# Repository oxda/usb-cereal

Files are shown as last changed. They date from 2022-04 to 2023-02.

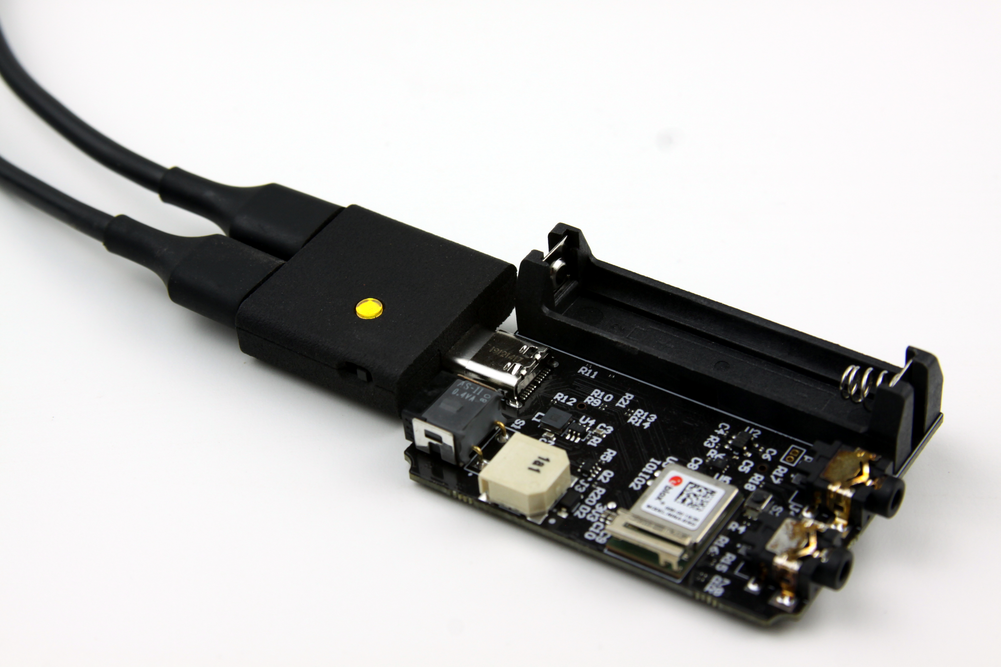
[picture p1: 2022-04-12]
img/edit_IMG_1961.JPG

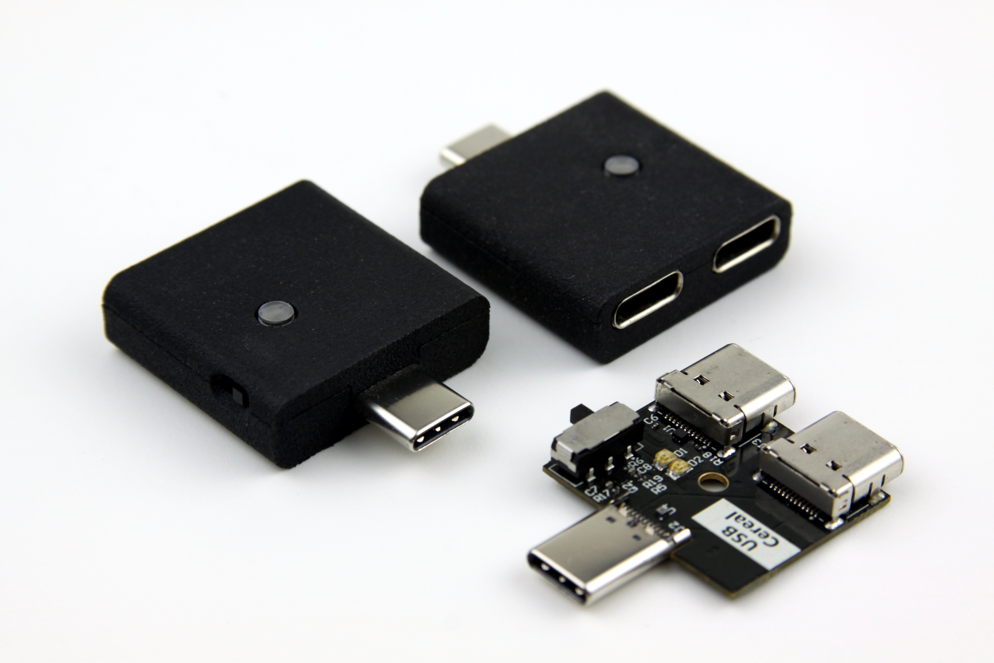
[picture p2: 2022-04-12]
img/edit_IMG_1957.JPG

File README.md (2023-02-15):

# USB-Cereal
USB-Cereal is a powerful, fully open source development tool that simplifies testing, development, debugging, and manufacturing of devices that utilize USB-C. Using USB-C’s extended capabilities this unique hardware saves time and effort through simplified debug and factory log capture, as well as firmware update procedures.

**Availability:** CrowdSupply campaign: https://www.crowdsupply.com/0xda/usb-cereal

**Documentation:** [This repo's wiki](https://github.com/oxda/usb-cereal/wiki).

**Repo structure**
- /docs [WIP] contains PDF schematics and usage instructions.
- /mcad [WIP] contains mechanical enclosure.
- /ecad [WIP] contains entire USB-Cereal project done in Altium.

**FT232RQ vs FT232RNQ vs CP2102N**
As FTDI chips have intermittent supply issues we have also qualified CP2102N for the application. This IC is widely available, and is generally equally well equipped and compatible with major OSes. 

# Important Notes
Initial release contains a mistake where CC1/CC2 pins are tied together and share a single 5.1k pull-down resistor. This causes the USB-Cereal to not be compatible with the full USB-C cables. 0xDA's devices have corrected this mistake, but please beware if you have forked the design earlier.

# License
All the work is licensed under Apache 2.0 license. Changes from the original project: BOM optimization, layout adjustments, addition of the CP2102N and FT232RNQ versions.

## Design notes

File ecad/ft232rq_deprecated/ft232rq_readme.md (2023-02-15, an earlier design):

USB-Cereal ECAD files for FT232RQ variant.

**Note:** The design contains several mistakes - the CC1/CC2 share a legacy mode resistor, while they should be split into two. The overvoltage clamp presents too much capacitance on the TX/RX lines which prevents datarates above 576000.

**The design is frozen and deprecated. FT232RQ is an NRND component.** Please see updated FT232RNQ variant for the latest designs.

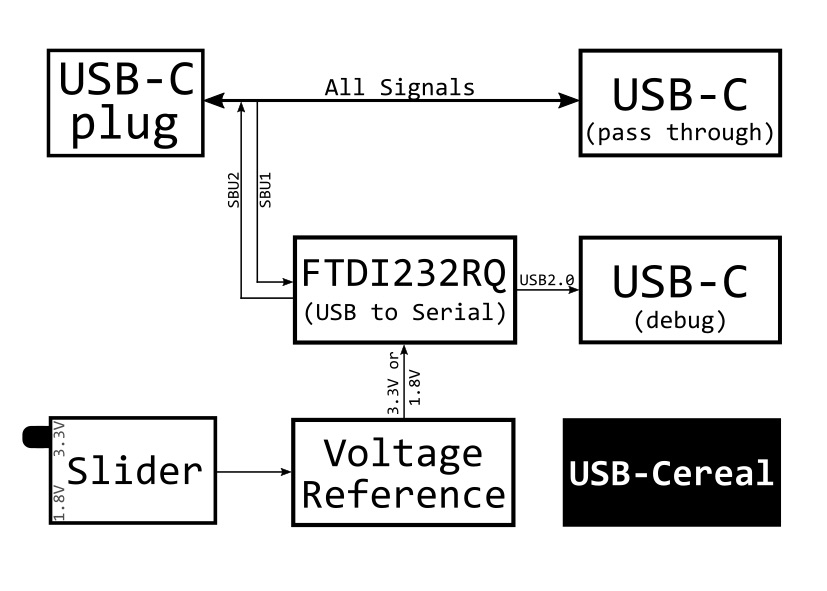
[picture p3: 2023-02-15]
img/usb-cereal-diagram.jpg

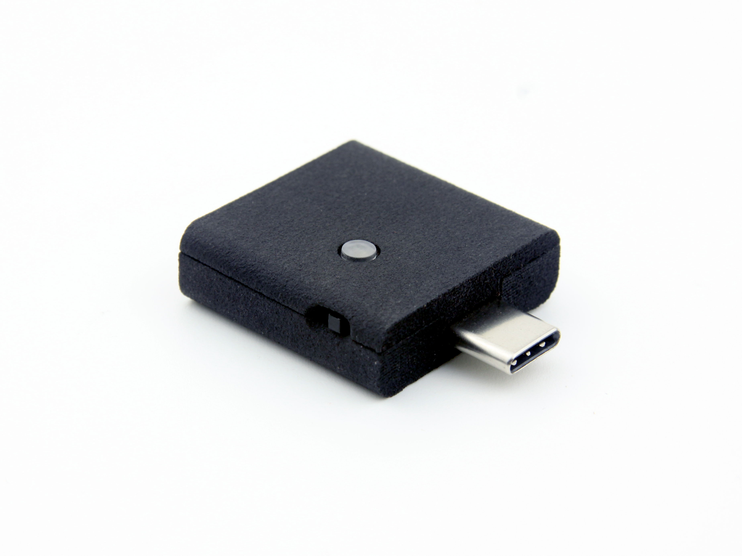
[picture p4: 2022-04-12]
img/edit_IMG_1848.JPG

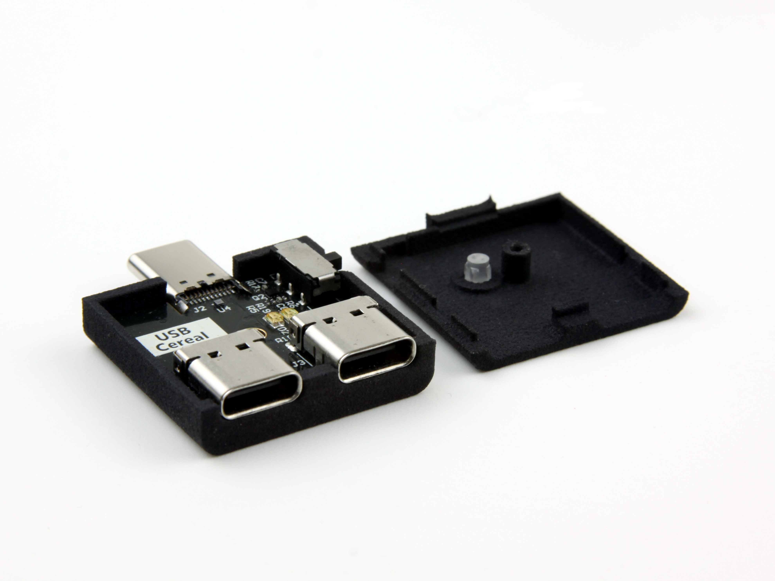
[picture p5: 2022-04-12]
img/edit_IMG_1966.JPG

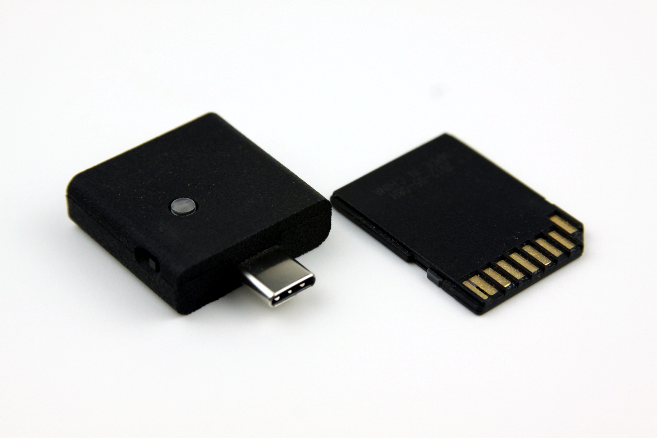
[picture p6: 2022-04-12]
img/edit_IMG_1954.JPG

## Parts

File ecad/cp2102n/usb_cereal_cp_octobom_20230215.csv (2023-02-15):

Query | Qty | Manufacturer | MPN | Part Description | Description | Schematic Reference
GCM155C71A105KE38D | 3 | Murata | GCM155C71A105KE38D | Multilayer Ceramic Capacitor, 1 uF, 10 V, ± 10%, X7S, 0402 [1005 Metric] | CAP CER 1UF 10V X7S 0402 | C1, C9, C10
GRM152R61A104KE19D | 2 | Murata | GRM152R61A104KE19D | Multilayer Ceramic Capacitor, 0.1 uF, 10 V, ± 10%, X5R, 0402 [1005 Metric] | CAP CER 0.1UF 10V X5R 0402 | C2, C5
ZRB15XR61A475KE01D | 2 | Murata | ZRB15XR61A475KE01D | Multilayer Ceramic Capacitor, 4.7 uF, 10 V, ± 10%, X5R, 0402 [1005 Metric] | CAP CER 4.7UF 10V X5R 0402 | C3, C4
GCM155R71E103KA37D | 1 | Murata | GCM155R71E103KA37D | Multilayer Ceramic Capacitor, 0.01 uF, 25 V, ± 10%, X7R, 0402 [1005 Metric] | CAP CER 10000PF 25V X7R 0402 | C6
LTST-C171GKT | 1 | Lite-On | LTST-C171GKT | LED Low-Power Uni-Color Green 565nm 2.1V 2-Pin Chip LED T/R | LED | D1
LTST-C171KSKT | 1 | Lite-On | LTST-C171KSKT | Yellow 2 x 1.25 x 0.8 mm 130° Water Clear 50 mcd 2 V LED Surface Mount | LED | D2
UJ32-C-H-G-SMT-TR | 2 | CUI Devices | UJ32-C-H-G-SMT-TR | Type C, USB 3.2 Gen 2x2, 20 Gbps, 20 Vac, 5 A, Horizontal, Gold Flash, Surface Mount, USB Receptacle | Type C, USB 3.1 Gen 2, 5 A, Right Angle, Surface Mount _SMT_ , USB Receptacle | J1, J3
USB4155-03-C | 1 | Global Connector Technology | USB4155-03-C | Usb Conn, 3.1 Type C, Plug, 24POS, SMT Rohs Compliant: Yes |  | J2
ERJ-2GE0R00X | 3 | Panasonic | ERJ-2GE0R00X | SMD Chip Resistor, Jumper, 0 ohm, 100 mW, 0402 [1005 Metric], Thick Film, General Purpose | RES SMD 0.0OHM JUMPER 1/10W 0402 | R1, R2, R16
ERJ-PA2F1001X | 1 | Panasonic | ERJ-PA2F1001X | Res Thick Film 0402 1K Ohm 1% 1/5W ±100ppm/°C Molded SMD Punched Paper T/R | RES SMD 1K OHM 1% 1/5W 0402 | R5
ERJ-2RKF2700X | 1 | Panasonic | ERJ-2RKF2700X | Res Thick Film 0402 270 Ohm 1% 0.1W(1/10W) +/-100ppm/C Molded SMD Automotive Punched T/R | RES SMD 270 OHM 1% 1/10W 0402 | R6
ERJ-2RKF5362X | 2 | Panasonic | ERJ-2RKF5362X | Res Thick Film 0402 53.6K Ohm 1% 1/10W ±100ppm/°C Molded SMD SMD Punched Carrier T/R | RES SMD 53.6K OHM 1% 1/10W 0402 | R9, R10
ERJ-2RKF2212X | 3 | Panasonic | ERJ-2RKF2212X | Resistor Thick Film 0402 22.1K Ohm 1% 0.1W (1/10W) ±100ppm/C Molded Surface Mount Automotive | RES SMD 22.1K OHM 1% 1/10W 0402 | R11, R15, R20
ERJ-2RKF3012X | 1 | Panasonic | ERJ-2RKF3012X | Res Thick Film 0402 30.1K Ohm 1% 1/10W +/-100ppm/ßC Molded SMD Punched Carrier T/R | RES SMD 30.1K OHM 1% 1/10W 0402 | R12
ERJ-2RKF5101X | 2 | Panasonic | ERJ-2RKF5101X | Res Thick Film 0402 5.1K Ohm 1% 1/10W ±100ppm/°C Molded SMD Punched Carrier T/R | RES SMD 5.1K OHM 1% 1/10W 0402 | R18, R22
ERJ-2RKF4752X | 1 | Panasonic | ERJ-2RKF4752X | Res Thick Film 0402 47.5K Ohm 1% 1/10W +/-100ppm/ßC Molded SMD Punched Carrier T/R | RES SMD 47.5K OHM 1% 1/10W 0402 | R21
JS202011JAQN | 1 | C&K Components | JS202011JAQN | Switch Slide ON ON DPDT Side Slide 0.3A 6VDC J-Bend SMD T/R | Slide Switch DPDT Surface Mount, Right Angle | S1
ESDR0502NMUTAG | 2 | onsemi | ESDR0502NMUTAG | ESDR0502N Series 5.5 V 0.3 pF Uni-Directional ESD Suppressor Diode Array -UDFN-6 | Ultra Low Capacitance ESD Protection Array for High Speed Data Line Protection, 6-Pin UDFN, Pb-Free, Tape and Reel | U1, U4
TPS77401DGK | 1 | Texas Instruments | TPS77401DGK | LDO Regulator Pos 1.5V to 5.5V 0.25A 8-Pin VSSOP Tube | Single Output Fast Transient Response LDO, 250 mA, Adjustable 1.5 to 5.5 V Output, 2.7 to 10 V Input, with Power Good Output, 8-pin MSOP (DGK), -40 to 125 degC, Green (RoHS & no Sb/Br) | U2
CP2102N-A02-GQFN24R | 1 | Silicon Labs | CP2102N-A02-GQFN24R | Interface IC full speed USB to UART bridge USB 2.0 3.3V, CP2102N-A02-GQFN24R, VFQFN-24 | USB Bridge, USB to UART USB 2.0 UART Interface 24-QFN _4x4_ | U3

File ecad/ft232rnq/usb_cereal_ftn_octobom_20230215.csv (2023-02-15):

Query | Qty | Manufacturer | MPN | Part Description | Description | Schematic Reference
JS202011JAQN | 1 | C&K Components | JS202011JAQN | Switch Slide ON ON DPDT Side Slide 0.3A 6VDC J-Bend SMD T/R | Slide Switch DPDT Surface Mount, Right Angle | S1
UJ32-C-H-G-SMT-TR | 2 | CUI Devices | UJ32-C-H-G-SMT-TR | Type C, USB 3.2 Gen 2x2, 20 Gbps, 20 Vac, 5 A, Horizontal, Gold Flash, Surface Mount, USB Receptacle | Type C, USB 3.1 Gen 2, 5 A, Right Angle, Surface Mount _SMT_ , USB Receptacle | J1, J3
FT232RNQ | 1 | FTDI | FT232RNQ-REEL | USB to Full Handshake UART Interface QFN32 (not offered in your region) | USB Bridge, USB to UART USB 2.0 UART Interface 32-QFN _5x5_ | U3
DX07P024AJ1R1500 | 1 | JAE Electronics | DX07P024AJ1R1500 | Conn Plug USB3.1 Typec Brd Edge | USB-C _USB TYPE-C_ USB 3.1 _USB 3.1 Gen 2, Superspeed+_ Plug Connector 24 Position Board Edge, Straddle Mount | J2
LTST-C171GKT | 1 | Lite-On | LTST-C171GKT | LED Low-Power Uni-Color Green 565nm 2.1V 2-Pin Chip LED T/R | LED | D1
LTST-C171KSKT | 1 | Lite-On | LTST-C171KSKT | Yellow 2 x 1.25 x 0.8 mm 130° Water Clear 50 mcd 2 V LED Surface Mount | LED | D2
GRM033R60J105MEA2D | 4 | Murata | GRM033R60J105MEA2D | Multilayer Ceramic Capacitor, 1 uF, 6.3 V, ± 20%, X5R, 0201 [0603 Metric] | CAP CER 1UF 6.3V X5R 0201 | C1, C2, C9, C10
GRM033R61A103KA01J | 1 | Murata | GRM033R61A103KA01J | 0201 10 nF 10 V ±10% Tolerance X5R SMT Multilayer Ceramic Capacitor | CAP CER 10000PF 10V X5R 0201 | C6
GRM033R61A104KE15D | 2 | Murata | GRM033R61A104KE15D | Multilayer Ceramic Capacitor, 0.1 uF, 10 V, ± 10%, X5R, 0201 [0603 Metric] | CAP CER 0.1UF 10V X5R 0201 | C3, C5
GRM033R61A225KE47D | 2 | Murata | GRM033R61A225KE47D | Multilayer Ceramic Capacitor, 2.2 uF, 10 V, ± 10%, X5R, 0201 [0603 Metric] | CAP CER 2.2UF 10V X5R 0201 | C7, C8
GRM035R60J475ME15D | 1 | Murata | GRM035R60J475ME15D | Multilayer Ceramic Capacitor, 4.7 uF, 6.3 V, ± 20%, X5R, 0201 [0603 Metric] | CAP CER 4.7UF 6.3V X5R 0201 | C4
PMDXB600UNEZ | 2 | Nexperia | PMDXB600UNEZ | Dual Mosfet, Dual N Channel, 600 Ma, 20 V, 0.47 Ohm, 4.5 V, 700 Mv | Dual N-Channel Trench MOSFET, 20 V, 0.6 A, -55 to 150 degC, 8-Pin SOT1216 | Q1, Q2
ESD7383NCTBG | 1 | onsemi | ESD7383NCTBG | ESD Protection, 3-Line, Very Low Capacitance, for USB | USB-OTG 3-Line Protection, 4-Pin WLCSP, Pb-Free, Tape and Reel | U4
ESDR0502NMUTAG | 1 | onsemi | ESDR0502NMUTAG | ESDR0502N Series 5.5 V 0.3 pF Uni-Directional ESD Suppressor Diode Array -UDFN-6 | Ultra Low Capacitance ESD Protection Array for High Speed Data Line Protection, 6-Pin UDFN, Pb-Free, Tape and Reel | U1
ERJ-1GEF3012C | 3 | Panasonic | ERJ-1GEF3012C | Res Thick Film 0201 30.1K Ohm 1% 1/20W ±200ppm/°C Molded SMD Pressed Carrier T/R | RES SMD 30.1K OHM 1% 1/20W 0201 | R12, R17, R19
ERJ-1GN0R00C | 5 | Panasonic | ERJ-1GN0R00C | ERJ Series 0201 0 Ohm 0.05 W Jumper Surface Mount Thick Film Chip Resistor | RES SMD 0.0OHM JUMPER 1/20W 0201 | R1, R2, R7, R8, R16
ERJ-1GNF1001C | 1 | Panasonic | ERJ-1GNF1001C | Res Thick Film 0201 1K Ohm 1% 0.05W(1/20W) ±200ppm/C Pad SMD Automotive T/R | RES SMD 1K OHM 1% 1/20W 0201 | R5
ERJ-1GNF2212C | 1 | Panasonic | ERJ-1GNF2212C | Res Thick Film 0201 22.1K Ohm 1% 1/20W ±200ppm/°C Molded SMD SMD T/R | RES SMD 22.1K OHM 1% 1/20W 0201 | R11
ERJ-1GNF2700C | 1 | Panasonic | ERJ-1GNF2700C | Res Thick Film 0201 270 Ohm 1% 1/20W ±200ppm/°C Molded SMD T/R | RES SMD 270 OHM 1% 1/20W 0201 | R6
ERJ-1GNF5101C | 1 | Panasonic | ERJ-1GNF5101C | Res Thick Film 0201 5.1K Ohm 1% 1/20W ±200ppm/°C Molded SMD Pressed Carrier T/R | RES SMD 5.1K OHM 1% 1/20W 0201 | R18
ERJ-1GNF5362C | 2 | Panasonic | ERJ-1GNF5362C | Res Thick Film 0201 53.6K Ohm 1% 1/20W ±200ppm/°C Molded SMD SMD T/R | RES SMD 53.6K OHM 1% 1/20W 0201 | R9, R10
ERJ-1GNJ103C | 1 | Panasonic | ERJ-1GNJ103C | Res Thick Film 0201 10K Ohm 5% 0.05W(1/20W) ±200ppm/C Pad SMD Automotive T/R | RES SMD 10K OHM 5% 1/20W 0201 | R20
ERJ-1GNJ472C | 1 | Panasonic | ERJ-1GNJ472C | Res Thick Film 0201 4.7K Ohm 5% 0.05W(1/20W) ±200ppm/C Pad SMD Automotive T/R | RES SMD 4.7K OHM 5% 1/20W 0201 | R15
ERJ-2GEJ620X | 2 | Panasonic | ERJ-2GEJ620X | Res Thick Film 0402 62 Ohm 5% 1/10W ±200ppm/°C Molded SMD Punched Carrier T/R | RES SMD 62 OHM 5% 1/10W 0402 | R3, R4
TPS77401DGK | 1 | Texas Instruments | TPS77401DGK | LDO Regulator Pos 1.5V to 5.5V 0.25A 8-Pin VSSOP Tube | Single Output Fast Transient Response LDO, 250 mA, Adjustable 1.5 to 5.5 V Output, 2.7 to 10 V Input, with Power Good Output, 8-pin MSOP (DGK), -40 to 125 degC, Green (RoHS & no Sb/Br) | U2

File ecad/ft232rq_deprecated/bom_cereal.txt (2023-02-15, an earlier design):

Comment	Description	Designator	Footprint	LibRef	Quantity

"1µF"	"CAP CER 1UF 6.3V X5R 0201"	"C1, C2, C9, C10"	"SMD-0201C"	"GRM033R60J105MEA2D"	"4"
"0.10µF"	"CAP CER 0.1UF 10V X5R 0201"	"C3, C5"	"SMD-0201C"	"GRM033R61A104KE15D"	"2"
"4.7µF"	"CAP CER 4.7UF 4V X5R 0402"	"C4"	"SMD-0402C"	"GRM153R60G475ME15D"	"1"
"10000pF"	"CAP CER 10000PF 10V X5R 0201"	"C6"	"SMD-0201C"	"GRM033R61A103KA01J"	"1"
"2.2µF"	"CAP CER 2.2UF 10V X5R 0201"	"C7, C8"	"SMD-0201C"	"GRM033R61A225KE47D"	"2"
"LTST-C171GKT"	"LED"	"D1"	"0805"	"LTST-C171GKT"	"1"
"LTST-C171KSKT"	"LED"	"D2"	"0805"	"LTST-C171KSKT"	"1"
"MBD54DWT1"	"Dual Schottky Barrier Diodes, 6-Pin SOT-363, Tape and Reel"	"D5"	"ONSC-SOT-363-6-419B-02_W_V"	"MBD54DWT1"	"1"
"DX07P024AJ1R1500"	"USB-C _USB TYPE-C_ USB 3.1 _USB 3.1 Gen 2, Superspeed+_ Plug Connector 24 Position Board Edge, Straddle Mount"	"J"	"JAE_DX07P024AJ1R1500"	"DX07P024AJ1R1500"	"1"
"12401598E4#2A"	"USB-C _USB TYPE-C_ USB 3.1 _USB 3.1 Gen 2, Superspeed+_ Receptacle Connector 24 Position Surface Mount, Right Angle; Through Hole"	"J?"	"AMPHENOL_12401598E4#2A"	"12401598E4#2A"	"2"
"PMDXB600UNEZ"	"Dual N-Channel Trench MOSFET, 20 V, 0.6 A, -55 to 150 degC, 8-Pin SOT1216"	"Q1, Q2"	"NXP-SOT1216_N"	"PMDXB600UNEZ"	"2"
"0.0"	"RES SMD 0.0OHM JUMPER 1/20W 0201"	"R1, R2, R7, R8, R16"	"SMD-0201-RES"	"ERJ-1GN0R00C"	"5"
"62"	"RES SMD 62 OHM 5% 1/10W 0402"	"R3, R4"	"SMD-0402-RES"	"ERJ-2GEJ620X"	"2"
"1k"	"RES SMD 1K OHM 1% 1/20W 0201"	"R5"	"SMD-0201-RES"	"ERJ-1GEF1001C"	"1"
"270"	"RES SMD 270 OHM 1% 1/20W 0201"	"R6"	"SMD-0201-RES"	"ERJ-1GEF2700C"	"1"
"53.6k"	"RES SMD 53.6K OHM 1% 1/20W 0201"	"R9, R10"	"SMD-0201-RES"	"ERJ-1GEF5362C"	"2"
"22.1k"	"RES SMD 22.1K OHM 1% 1/20W 0201"	"R11"	"SMD-0201-RES"	"ERJ-1GEF2212C"	"1"
"30.1k"	"RES SMD 30.1K OHM 1% 1/20W 0201"	"R12, R15, R17, R19"	"SMD-0201-RES"	"ERJ-1GEF3012C"	"4"
"5.1k"	"RES SMD 5.1K OHM 1% 1/20W 0201"	"R18"	"SMD-0201-RES"	"ERJ-1GEF5101C"	"1"
"JS202011JAQN"	"Slide Switch DPDT Surface Mount, Right Angle"	"S"	"JS202011JAQN"	"JS202011JAQN"	"1"
"416131160801"	"WS-DISV 1.27 mm small compact SMD Dip Switch with top tape"	"SW1"	"416131160801"	"416131160801"	"1"
"ESDR0502NMUTAG"	"Ultra Low Capacitance ESD Protection Array for High Speed Data Line Protection, 6-Pin UDFN, Pb-Free, Tape and Reel"	"U1"	"ONSC-UDFN-6-517AA-01_V"	"ESDR0502NMUTAG"	"1"
"TPS77401DGK"	"Single Output Fast Transient Response LDO, 250 mA, Adjustable 1.5 to 5.5 V Output, 2.7 to 10 V Input, with Power Good Output, 8-pin MSOP (DGK), -40 to 125 degC, Green (RoHS & no Sb/Br)"	"U2"	"TI-DGK8_N"	"TPS77401DGK"	"1"
"FT232RQ-Reel"	"USB UART Asynchronous Serial Data Transfer Chip, 32-pin QFN, Tape and Reel"	"U3"	"PQFN5X5-32_V"	"FT232RQ-Reel"	"1"

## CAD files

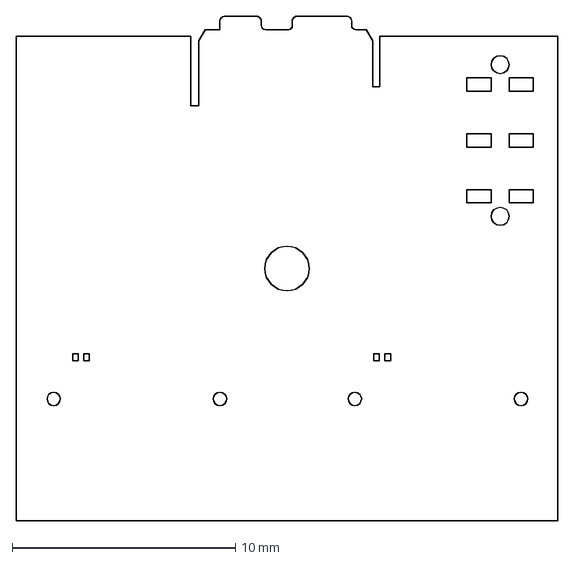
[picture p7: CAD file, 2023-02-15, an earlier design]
ecad/ft232rq_deprecated/dxf/v0.dxf
24.3 x 22.6 mm

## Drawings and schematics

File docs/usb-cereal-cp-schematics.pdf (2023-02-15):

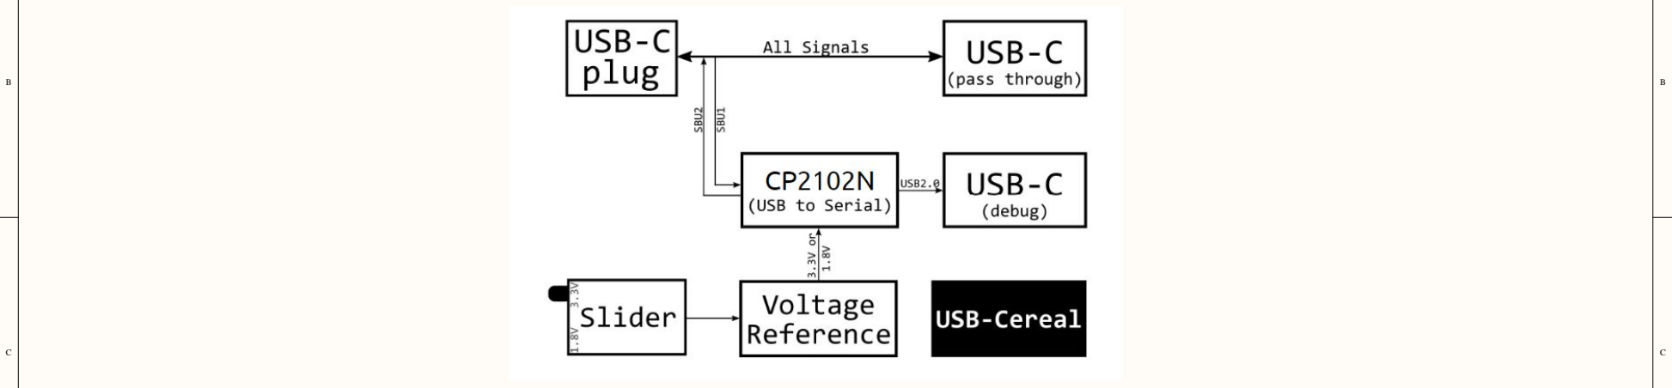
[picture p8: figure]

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
D | D
A | A
1 | 2
Title: USB-Cereal Diagram | Author: dnv
GPN: N/A | Revision: 1 | Size: Tabloid | Reviewers:
2/15/2023 | 10:57:07 AM
Date:
Time: | Sheet | of

Utility board that provides serial interface tapped into SBU lines, compatible with both 1.8V and 3.3V signalling.

Cereal - USB-C serial interface breakout for debugging/development purposes.

Copyright 2023 0xDA LLC, San Francisco, CA USA

Licensed under the Apache License, Version 2.0 (the "License"); you may not use this file except in compliance with the License. You may obtain a copy of the License at http://www.apache.org/licenses/LICENSE-2.0

Unless required by applicable law or agreed to in writing,software distributed under the License is distributed on an "AS IS" BASIS, WITHOUT WARRANTIES OR CONDITIONS OF ANY KIND, either express or implied. See the License for the specific language governing permissions and limitations under the License.

The Original Design Copyright Notice: Copyright 2020 Google LLC. Please see the online documentation at https://github.com/oxda/usb-cereal/wiki for additional information.

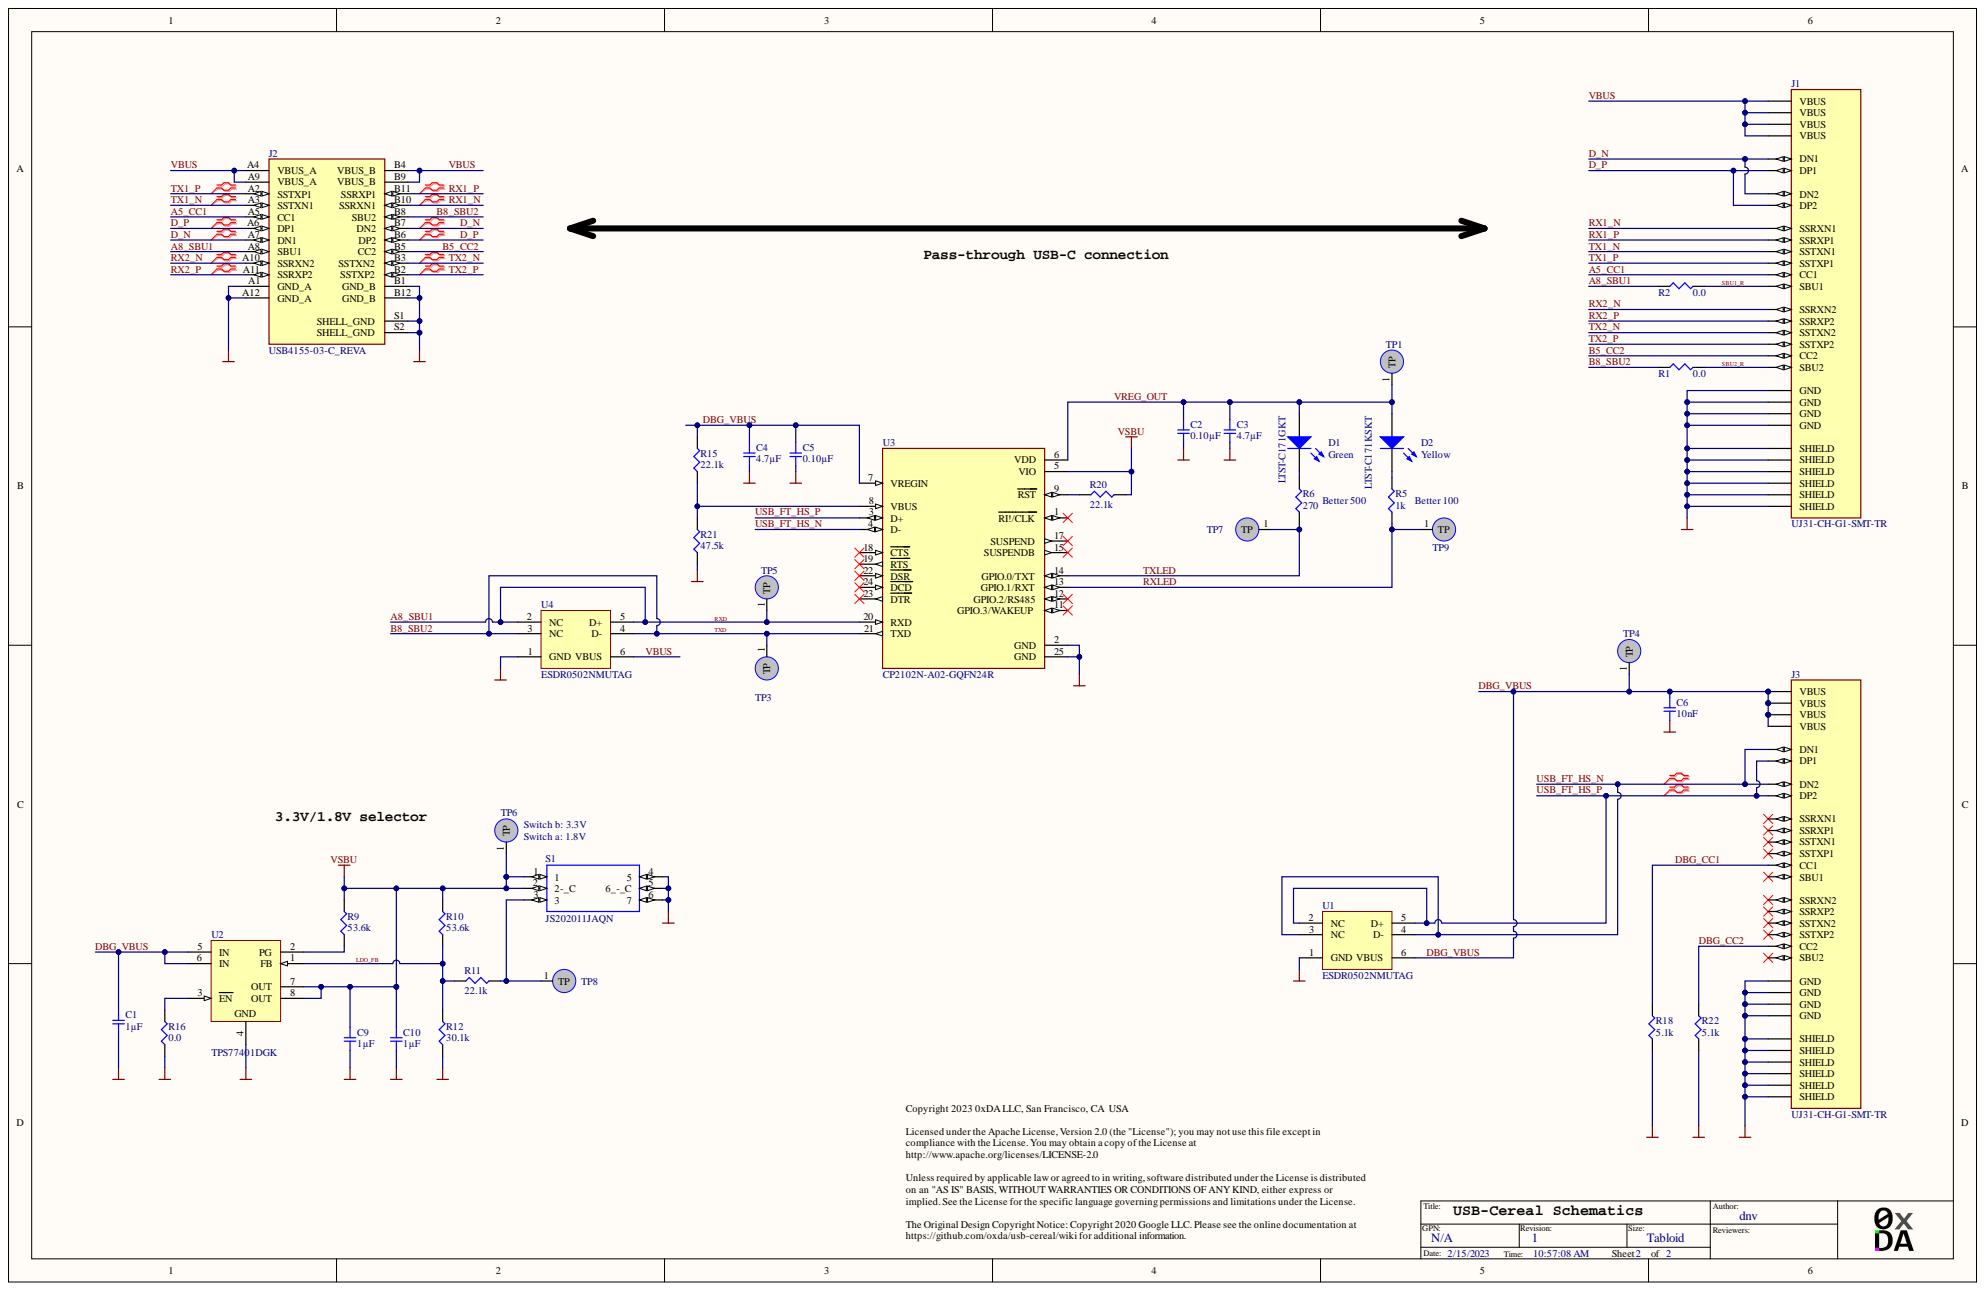
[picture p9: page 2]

Pass-through USB-C connection

Copyright 2023 0xDA LLC, San Francisco, CA USA

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

Title: USB-Cereal Schematics | Author: dnv

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

GPN: N/A | Revision: 1 | Size: Tabloid | Reviewers:

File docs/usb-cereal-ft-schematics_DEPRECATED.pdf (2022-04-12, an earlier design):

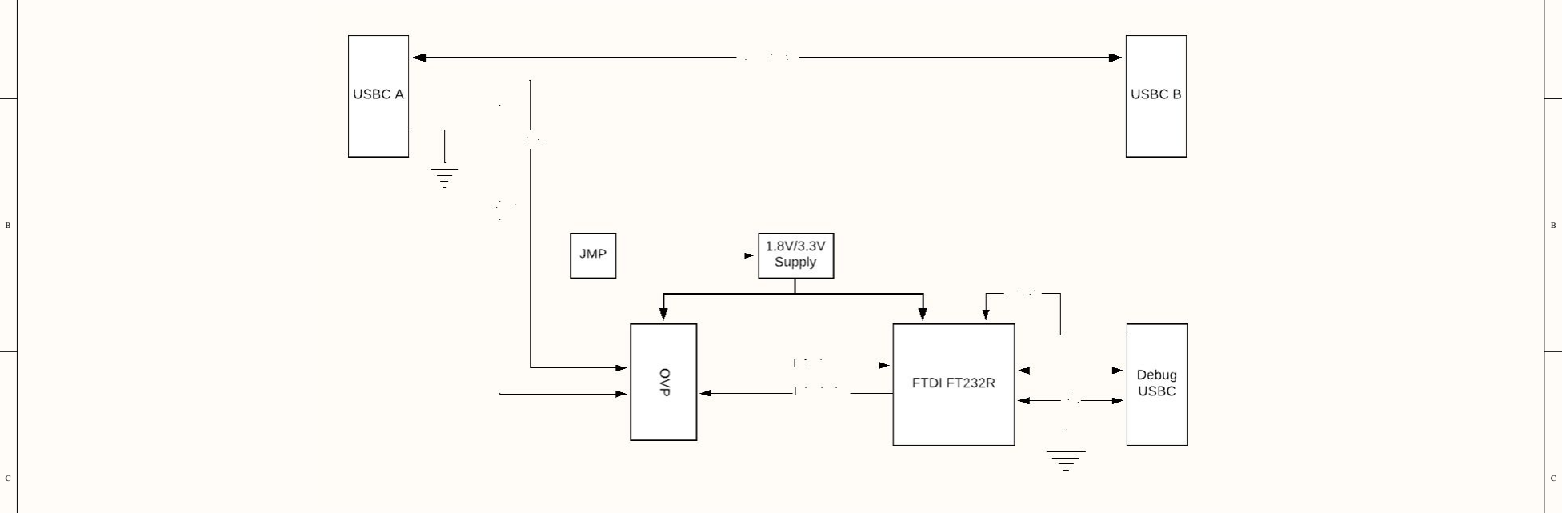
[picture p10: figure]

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
D | D
A | A
1 | 2
Title: USB-Cereal Diagram | Author: dnv
GPN: N/A | Revision: 1 | Size: Tabloid | Reviewers:
4/11/2022 | 8:58:16 PM
Date:
Time: | Sheet | of

Utility board that provides serial interface tapped into SBU lines, compatible with both 1.8V and 3.3V signalling.

Cereal - USB-C serial interface breakout for debugging/development purposes.

Unless required by applicable law or agreed to in writing,software distributed under the License is distributed on an "AS IS" BASIS, WITHOUT WARRANTIES OR CONDITIONS OF ANY KIND, either express or implied. See the License for the specific language governing permissions and limitations under the License.

Copyright 2022 0xDA, San Francisco, CA

Licensed under the Apache License, Version 2.0 (the "License"); you may not use this file except in compliance with the License. You may obtain a copy of the License at http://www.apache.org/licenses/LICENSE-2.0

The Original Design Copyright Notice: Copyright 2020 Google LLC

Changes from the original work:
1) S1 switch replaced.
2) D5A, D5B - Not staffed.

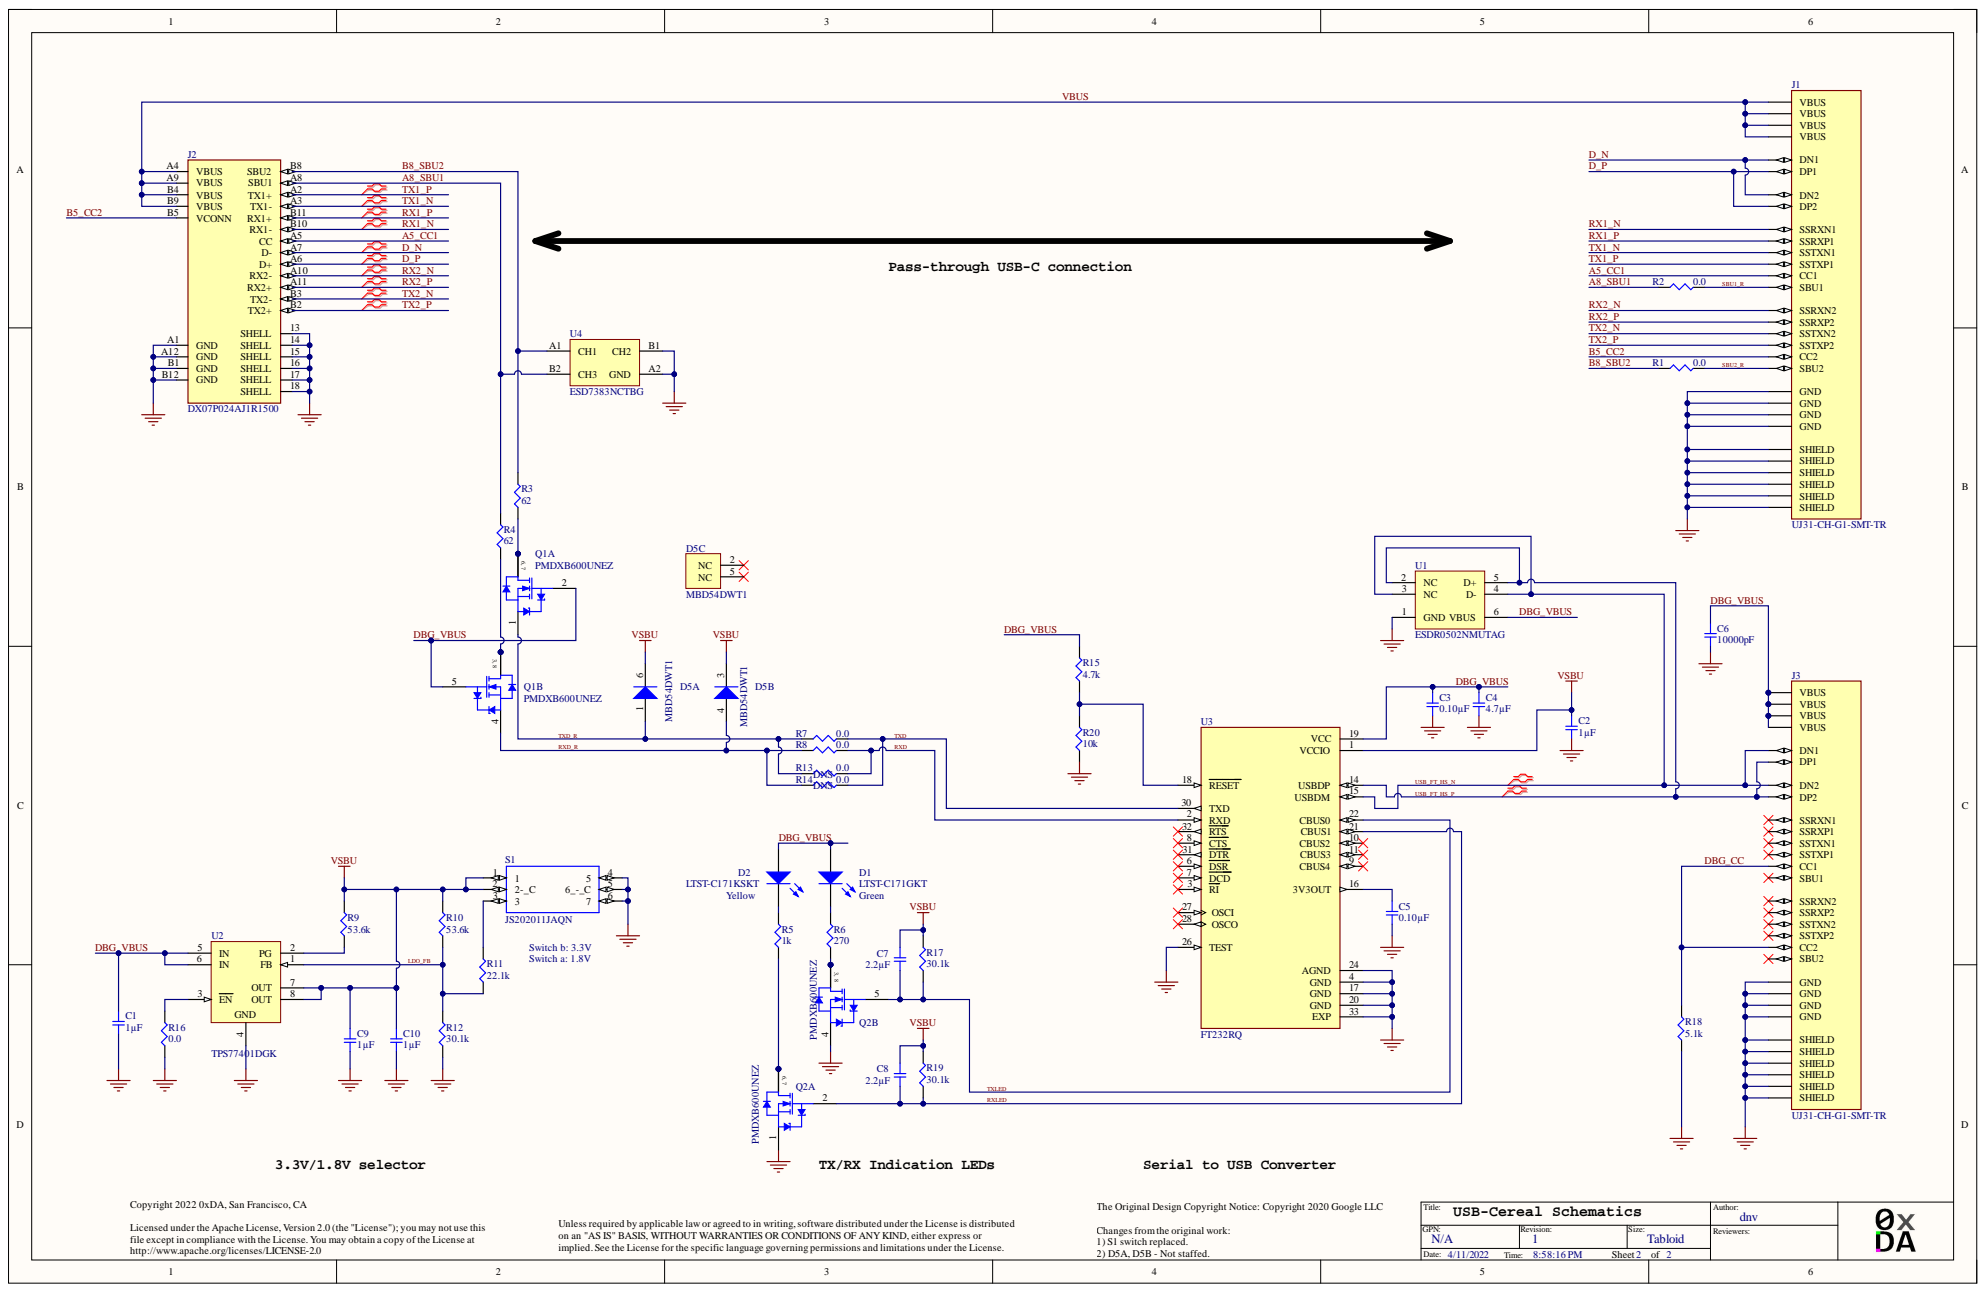
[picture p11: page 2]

A 9 | A 8 A 8 _ S B U 1
B 4 | A 2 T X 1 _ P
B 9 | A 3 T X 1 _ N

Title : USB-Cereal Schematics | Author : d n v

GP N : N/A | R evision: 1 | Siz e : T ab l o i d | R eviewe r s :

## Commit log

2022-04-12 usb-cereal oxda edition release
    [usb-cereal-sch.SchDoc, usb-cereal-sys.SchDoc, usb-cereal.PrjPCB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]
2023-02-15 CP2102N files added, old design files deprecated.
    [usb-cereal-cp-sch.SchDoc, usb-cereal-cp-sys.SchDoc, usb-cereal-cp.PrjPCB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]
